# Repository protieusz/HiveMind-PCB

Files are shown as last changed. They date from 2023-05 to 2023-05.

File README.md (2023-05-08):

# HiveMind-PCB
HiveMind "Untested" PCB version that was converted from the handwired version. 47 Keys QAZ-ish layout with a numpad in the center and fits a 60% keyboard travel case.
Please print at your own risk.  No support will be given.  Pcb was designed using EasyEDA and DRC shows no errors.  MCU used is the Pimoroni PGA2040. Routing is auto routed. Have fun and good luck.

UPDATE: May 7, 2023: Rev 2 gerbers uploaded and delete Rev 1.  Rev 1 had a mcu footprint center cut out that will render the pcb useless when using auto routing for traces.  Use Rev 2 gerbers but gerbers are still un-tested. Please print at your own risk!!!

2D view of the top pcb
TopGreen2DpcbHiveMind

2D view of the bottom pcb
BottomGreen2DpcbHiveMind

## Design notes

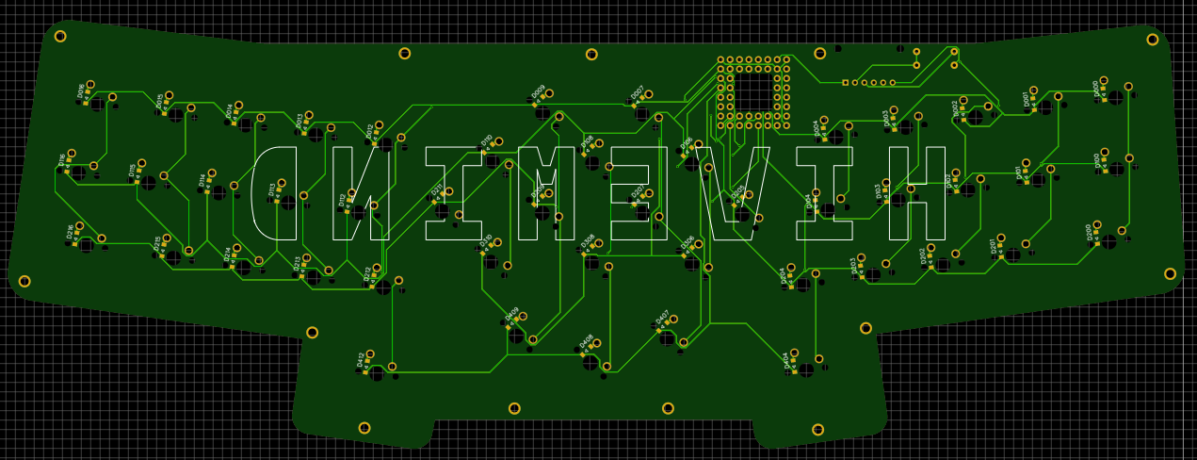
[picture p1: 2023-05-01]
HiveMind EasyEDA/BottomGreen2DpcbHiveMind.png

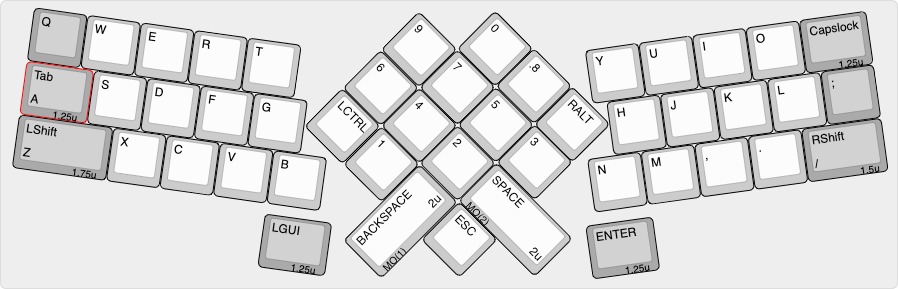
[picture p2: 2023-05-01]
KLE/matrix_v3.jpeg

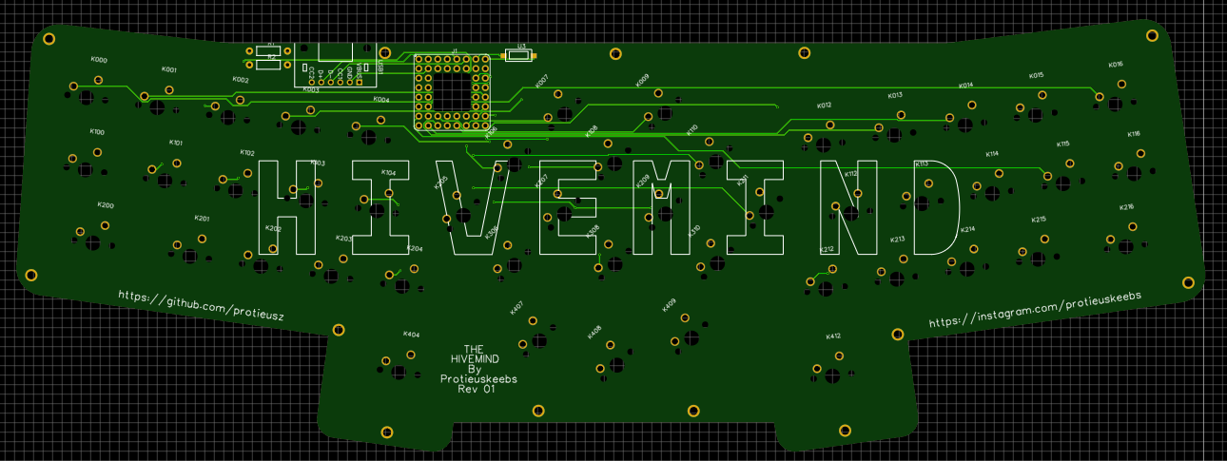
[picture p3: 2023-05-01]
HiveMind EasyEDA/TopGreen2DpcbHiveMind.png

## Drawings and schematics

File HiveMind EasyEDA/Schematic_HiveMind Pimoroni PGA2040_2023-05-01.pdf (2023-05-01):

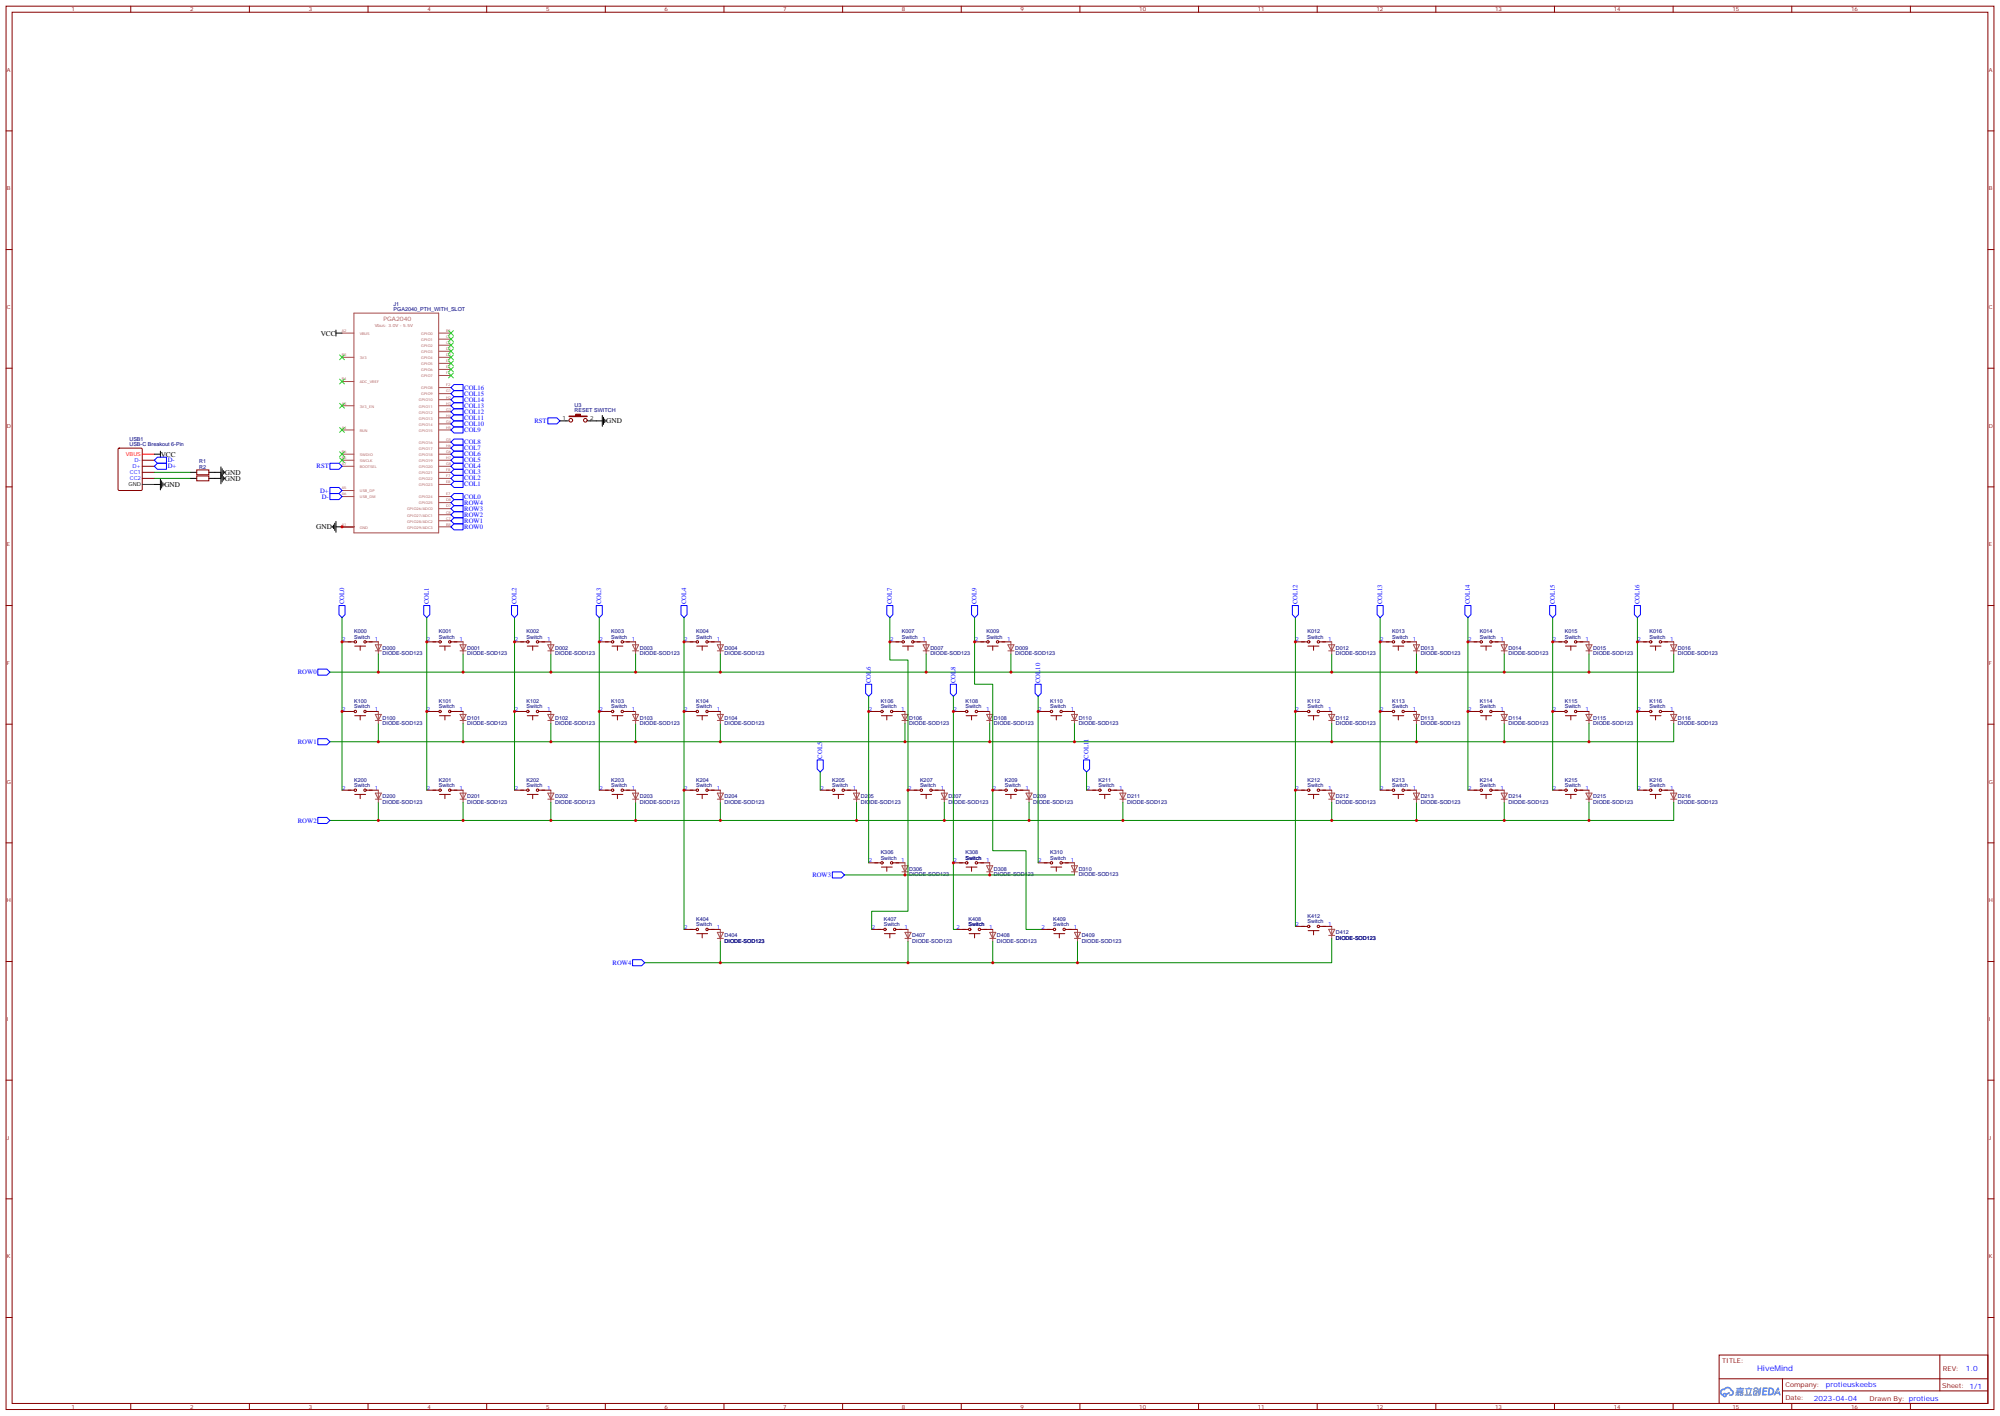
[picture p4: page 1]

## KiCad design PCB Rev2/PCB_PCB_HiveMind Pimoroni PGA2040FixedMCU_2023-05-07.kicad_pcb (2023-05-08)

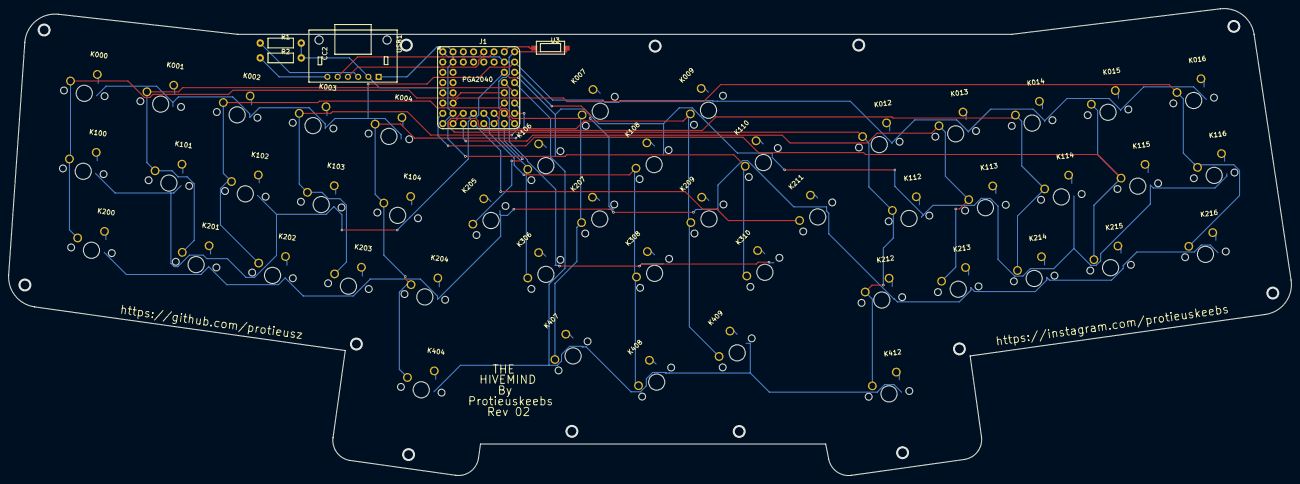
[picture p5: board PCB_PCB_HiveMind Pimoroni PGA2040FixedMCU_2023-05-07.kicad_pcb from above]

Board: 2 copper layers, 317.6 x 115.6 mm, 99 parts (0 on the bottom side), 76 nets.

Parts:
D000, D001, D002, D003, D004, D007, D009, D012, D013, D014, D015, D016, D100, D101, D102, D103, D104, D106, D108, D110, D112, D113, D114, D115, D116, D200, D201, D202, D203, D204, D205, D207, D209, D211, D212, D213, D214, D215, D216, D306, D308, D310, D404, D407, D408, D409, D412: DIODE-SOD123
J1: PGA2040; gge34507
K000, K001, K002, K003, K004, K007, K009, K012, K013, K014, K015, K016, K100, K101, K102, K103, K104, K106, K108, K110, K112, K113, K114, K115, K116, K200, K201, K202, K203, K204, K205, K207, K209, K211, K212, K213, K214, K215, K216, K306, K308, K310, K404, K407, K408, K409, K412: 100; CHERRY_MX_100_MILLMAX
R1, R2: 5.1KΩ(5101); AXIAL-0.4
U3: RESET SWITCH
USB1: CC2; USB-C_TH_BREAKOUT_6P

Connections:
COL0: J1.E7, K000.2, K100.2, K200.2
COL1: J1.E8, K001.2, K101.2, K201.2
COL2: J1.F7, K002.2, K102.2, K202.2
COL3: J1.F8, K003.2, K103.2, K203.2
COL4: J1.G8, K004.2, K104.2, K204.2, K404.2
COL5: J1.H7, K205.2
COL6: J1.G6, K106.2, K306.2
COL7: J1.H6, K007.2, K207.2, K407.2
COL8: J1.G5, K108.2, K308.2, K408.2
COL9: J1.H5, K009.2, K209.2, K409.2
COL10: J1.G4, K110.2, K310.2
COL11: J1.H4, K211.2
COL12: J1.G3, K012.2, K112.2, K212.2, K412.2
COL13: J1.H3, K013.2, K113.2, K213.2
COL14: J1.H2, K014.2, K114.2, K214.2
COL15: J1.G1, K015.2, K115.2, K215.2
COL16: J1.F2, K016.2, K116.2, K216.2
D000_A: D000.A, K000.1
D003_A: D003.A, K003.1
D009_A: D009.A, K009.1
D013_A: D013.A, K013.1
D014_A: D014.A, K014.1
D016_A: D016.A, K016.1
D101_A: D101.A, K101.1
D102_A: D102.A, K102.1
D104_A: D104.A, K104.1
D106_A: D106.A, K106.1
D110_A: D110.A, K110.1
D112_A: D112.A, K112.1
D115_A: D115.A, K115.1
D201_A: D201.A, K201.1
D202_A: D202.A, K202.1
D204_A: D204.A, K204.1
D205_A: D205.A, K205.1
D207_A: D207.A, K207.1
D211_A: D211.A, K211.1
D212_A: D212.A, K212.1
D215_A: D215.A, K215.1
D308_A: D308.A, K308.1
D408_A: D408.A, K408.1
D412_A: D412.A, K412.1
D+: J1.A5, USB1.3
D-: J1.A6, USB1.2
GND: J1.A1, J1.A8, J1.B2, J1.B7, J1.G2, J1.G7, J1.H1, J1.H8, R1.2, R2.2, U3.2, USB1.6
K001_1: D001.A, K001.1
K002_1: D002.A, K002.1
K004_1: D004.A, K004.1
K007_1: D007.A, K007.1
K012_1: D012.A, K012.1
K015_1: D015.A, K015.1
K100_1: D100.A, K100.1
K103_1: D103.A, K103.1
K108_1: D108.A, K108.1
K113_1: D113.A, K113.1
K114_1: D114.A, K114.1
K116_1: D116.A, K116.1
K200_1: D200.A, K200.1
K203_1: D203.A, K203.1
K209_1: D209.A, K209.1
K213_1: D213.A, K213.1
K214_1: D214.A, K214.1
K216_1: D216.A, K216.1
K306_1: D306.A, K306.1
K310_1: D310.A, K310.1
K404_1: D404.A, K404.1
K407_1: D407.A, K407.1
K409_1: D409.A, K409.1
ROW0: D000.C, D001.C, D002.C, D003.C, D004.C, D007.C, D009.C, D012.C, D013.C, D014.C, D015.C, D016.C, J1.B8
ROW1: D100.C, D101.C, D102.C, D103.C, D104.C, D106.C, D108.C, D110.C, D112.C, D113.C, D114.C, D115.C, D116.C, J1.C7
ROW2: D200.C, D201.C, D202.C, D203.C, D204.C, D205.C, D207.C, D209.C, D211.C, D212.C, D213.C, D214.C, D215.C, D216.C, J1.C8
ROW3: D306.C, D308.C, D310.C, J1.D7
ROW4: D404.C, D407.C, D408.C, D409.C, D412.C, J1.D8
RST: J1.A7, U3.1
USB1_4: R1.1, USB1.4
USB1_5: R2.1, USB1.5
VCC: J1.A2, USB1.1

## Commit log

2023-05-01 Add gerbers, schematic & pcb Kicad converted
    [PCB_PCB_HiveMind Pimoroni PGA2040SilkscreenPattern_2023-05-01.kicad_pcb]
2023-05-08 Fix mcu cut out
2023-05-08 Add kicad converted files for Rev 2
    [PCB_PCB_HiveMind Pimoroni PGA2040FixedMCU_2023-05-07.kicad_pcb]
2023-05-08 Update with Rev 2 gerber changes
